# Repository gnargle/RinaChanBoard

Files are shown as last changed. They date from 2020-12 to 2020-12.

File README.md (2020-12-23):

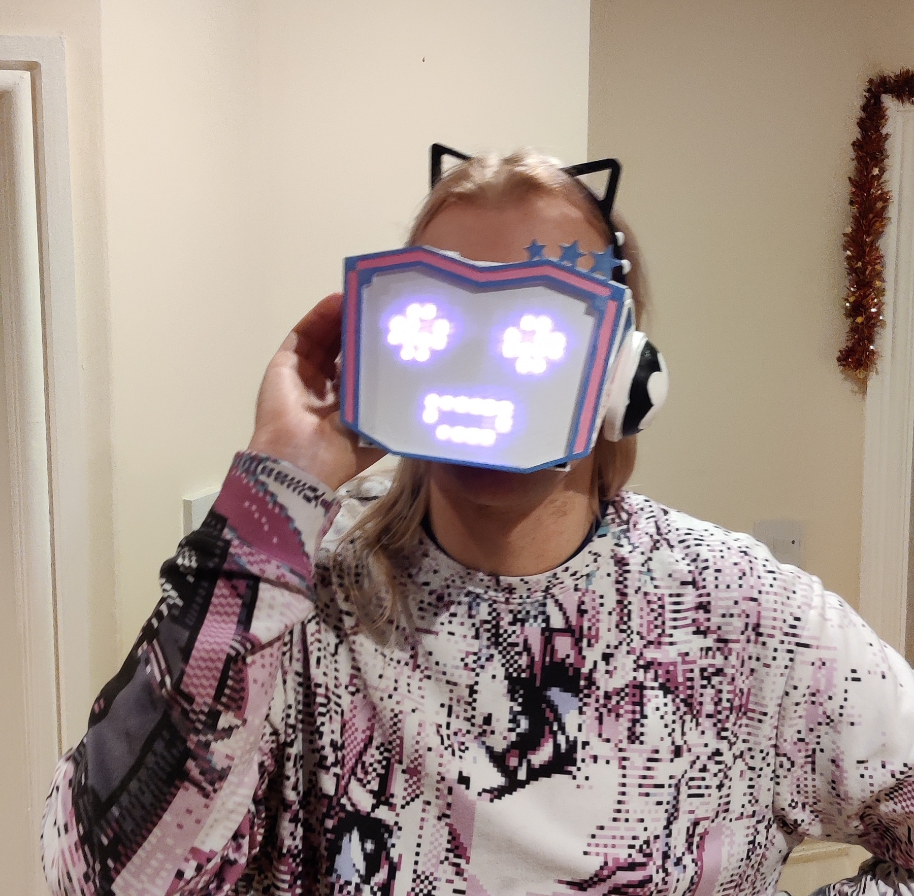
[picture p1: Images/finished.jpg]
Me wearing my new Rina-Chan Board!

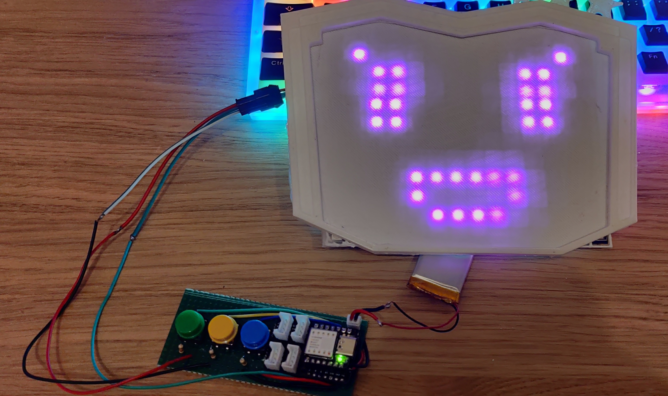
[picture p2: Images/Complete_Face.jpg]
Rina-Chan Board, Glowing and Smiling!


# RinaChanBoard
 Code, STLs and info to create a working Rina-Chan Board from Love Live!
 
## The Headset Model

The headset model was purchased from [Etsy](https://www.etsy.com/uk/listing/722676367/love-live-pdp-rina-tennoji-headset?transaction_id=2130833114). It's a brilliant model and fitted the exact purpose I needed it for. I highly recommend it.

The only STLs I am including are ones I personally modified to fit the use case (that is, creating a blank board and adding a grid to it). I am also including the diffuser.scad that I used - this is from thingiverse and is freely available. Use OpenSCAD to modify it to produce the size of grid you need, then attach it to the blank_plate.stl to create your grid. blank_grid.stl is the grid for the overlapped LED boards I used attached to the blank plate already.

Both are janky as hell, becasuse I don't know anything about modelling. 

## Required Hardware 
* Seeduino Xiao - This is the smallest arduino-compatible board I've found. https://www.seeedstudio.com/Seeeduino-XIAO-Arduino-Microcontroller-SAMD21-Cortex-M0+-p-4426.html
* 4x 8x8 WS2812B RGB LED boards - these will overlap but gives you a 14x13 LED area. It's enough to get good looking expressions for both eyes and face. You can also use 120 LED/m strips and manually lay them out and solder them. This will likely produce a better result, but the STL grid is not designed for that so you'll have to modify the blank plate yourself. https://www.aliexpress.com/item/32671025605.html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,searchweb201602_,searchweb201603_
* 3x push buttons. One each for selecting mouth and eyes, and one for confirming your selection. I didn't have any in so I bought this, which comes with button caps too. They are a little big so you might prefer smaller ones. https://www.amazon.co.uk/gp/product/B07Q22YP41/ref=ppx_yo_dt_b_asin_title_o04_s00?ie=UTF8&psc=1
* 3x 10k resistors - to tie the ground pin of the buttons.
* Wires, solder, etc
* OPTIONAL: Seeeduino Grove battery board. This is technically optional but I *highly* recommend it as it has a built in battery management board, with very little increase in used space. https://wiki.seeedstudio.com/Grove-Shield-for-Seeeduino-XIAO-embedded-battery-management-chip/
* OPTIONAL: LiPo battery. Doesn't need to be very big, I used this. https://www.amazon.co.uk/gp/product/B08215N9R8/ref=ppx_yo_dt_b_asin_image_o08_s01?ie=UTF8&psc=1
* OPTIONAL: JST connectors or Molex connectors for the battery. So you can easily disconnect it if needed. The above battery comes with a molex, I bought these JST connectors so had to solder the new connector on to it anyway because I'm an idiot and can't read. https://www.amazon.co.uk/gp/product/B07449V33P/ref=ppx_yo_dt_b_asin_image_o08_s00?ie=UTF8&psc=1

If you're not going to use the grove battery board you can roll your own battery solution but I found this was the easiest solution with very few drawbacks.

## Designing the Expressions

I used a hacked-together google docs sheet that I coloured in manually and copied the numbers out manually into arrays. There's definitely more clever ways of doing this but I hate working with spreadsheets so I was happy to be manual on this. What is useful in this case is I marked with outlines where the overlaps between the panels are. You can find my doc [here](https://docs.google.com/spreadsheets/d/1Beuz8oJ9O0KB6ERlhMPzRE0FvdVzDu4BHBZgB-ASULc/edit?usp=sharing). Use the adjusted spacing sheet - the first sheet is a full 16x16 matrix which has enough room for full model-accurate expressions. If you're going to use dense strips, I recommend a layout like this. Otherwise, use "adjusted spacing", sheet 2 ("Corrected Numbers") was an intermediary after I got the boards to actually layout the panels correctly, before I worked out any overlapping.

## Assembling the Board 

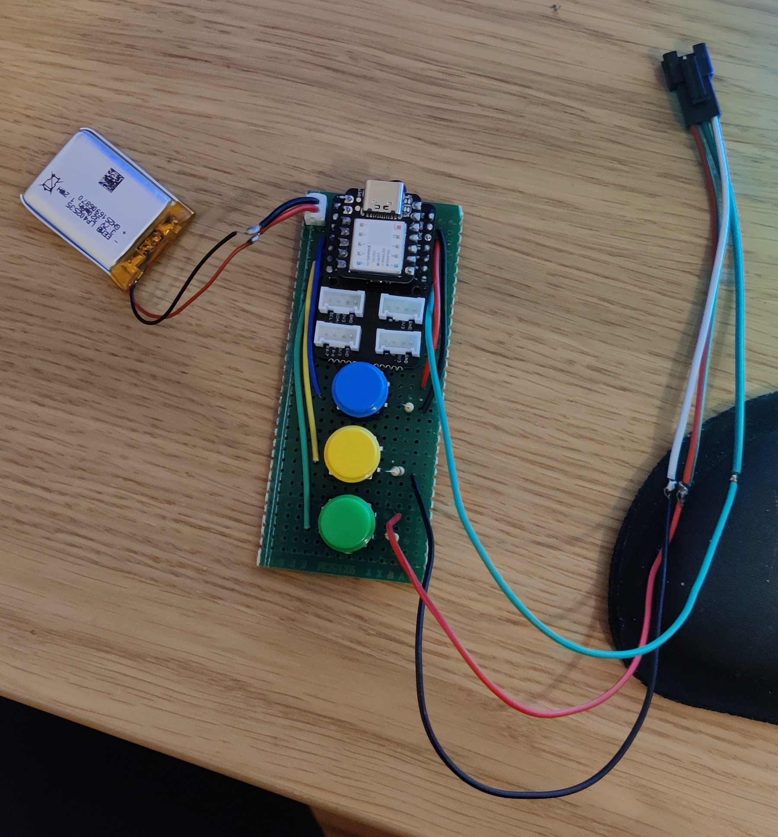
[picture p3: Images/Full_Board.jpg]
Full Board

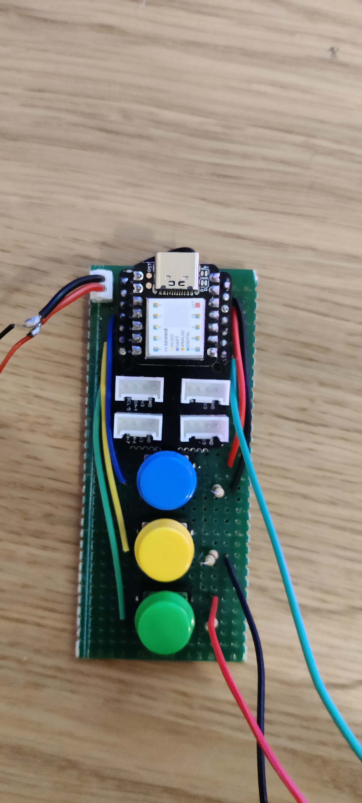
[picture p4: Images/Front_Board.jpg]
Front of the Board

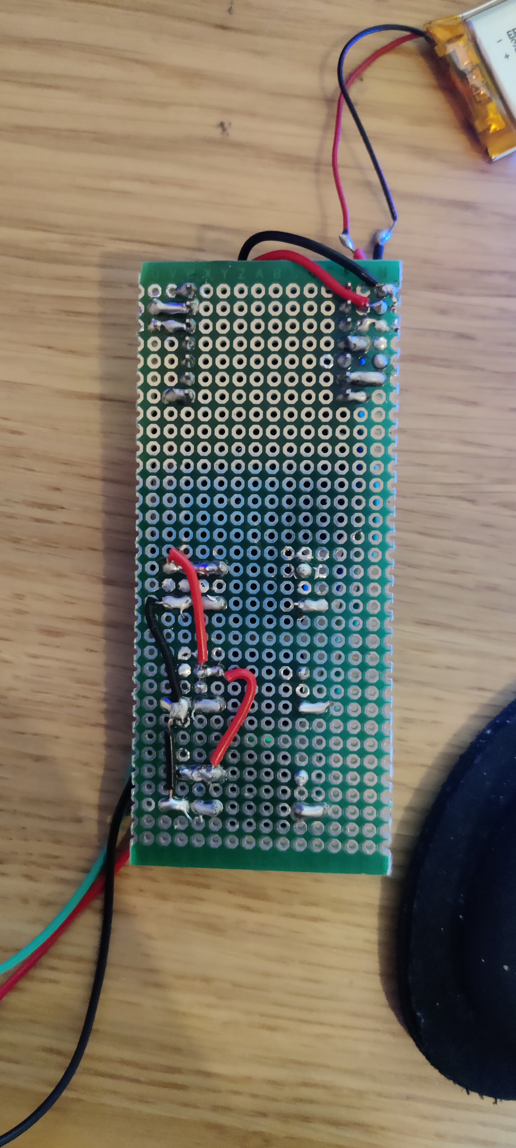
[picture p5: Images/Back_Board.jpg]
Back of the Board


My board is kind of a mess but the pinout is simple. Pins 3,5 and 6 are the buttons (these are modifiable consts in the code - they were originally 4,5 and 6 but I stripped the metal from the contact next to 4) and pin 7 (again, modifiable) is the output data line for the LED panels. The panels are 3-wire WS2812Bs, PWR/DIN/GRN. The ones I'm using run off 3.3v just fine - if you're using the battery board I recommend this as tying it to the 5v pin shares the power between the Seeeduino and the board, causing dim LEDs.

Each button has one pin to 3.3V and one pin to ground through a 10k resistor (see arduino's [button page](https://www.arduino.cc/en/Tutorial/BuiltInExamples/Button) for more info). The output pin from the button is the one opposite the ground pin.

Once the board is assembled, you can mount the battery in the earcup and glue the board to the side of the headset. The thickness of the plate with the boards attached are such that you will need to glue that in place inbetween the two halves of the front board from the model.

## Assembling the Expression Plate

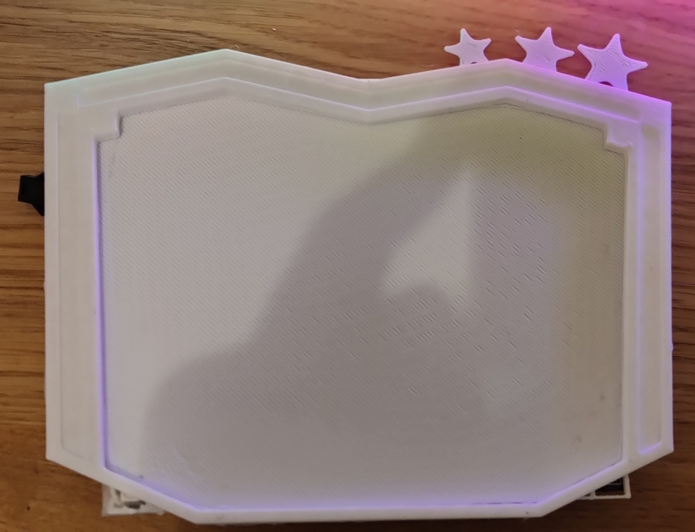
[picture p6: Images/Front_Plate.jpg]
Front Plate

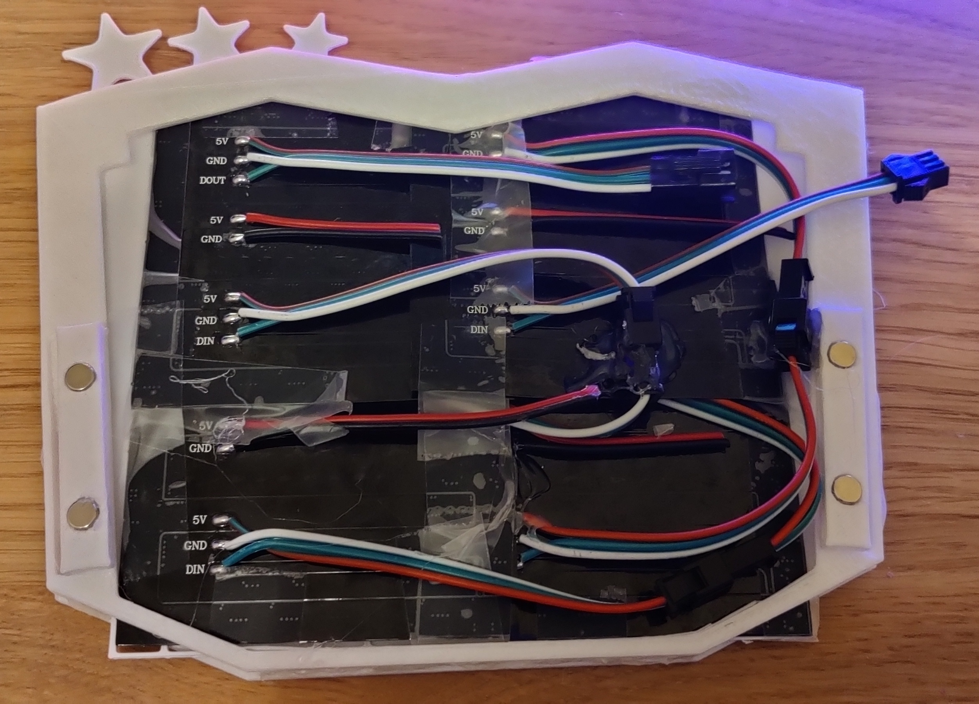
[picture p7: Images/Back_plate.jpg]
Back Plate


First, tape/glue your boards together in this format:

BOARD 1 | BOARD 4

BOARD 2 | BOARD 3

This means that in terms of LED order, the top left quadrant is first, then bottom left, then bottom right, then top right. Connect the DOUT -> DIN as appropriate along this pattern - the DIN for top left should be where the board connects, and the DOUT from top right should be unpopulated.

Then sandwich the two front plate holder parts either side of the LED plate and hot glue to hold it in place.

## The code

I've not worked on C++ in a long while (most of my work is in C# nowadays) and so I know the code is not the best it could be. the switch statements are particularly rubbish - I wanted to have a list of array pointers and just select them as appropriate but I couldn't get that working properly and the point of this project was the resultant prop, not nice code. So in this case, it working is enough for me. Feel free to PR a change that will make it cleaner if you want.

The code uses two Arduino librariers - FastLED and ezbutton. ezbutton works out the box but the version of FastLED in the arduino library does not support Seeeduino xiao (or didn't when I was working on this, anyway.). It's trivial to add this, though: (reproduced from https://forum.seeedstudio.com/t/xiao-using-fastled-to-control-ws2812b/252077/5 for posterity)

```
To get FastLED working you need to verify you are have the latest update to both the seeeduino boards as well as the FastLED library.

After verifying you have the most up to date versions of both.

Navigate into the FastLED library on your computer. Typically in C:\users<user name>\documents\arduino\libraries

you will want to navigate in the FastLED folder into the platforms then arm, then into d21, then edit the file called “fastpin_arm_d21”

Scroll down to around line 100 and paste this, and save.

#elif defined(SEEED_XIAO_M0)

#define MAX_PIN 10

_FL_DEFPIN( 0, 2,0); _FL_DEFPIN( 1, 4,0); _FL_DEFPIN( 2,10,0); _FL_DEFPIN( 3,11,0);

_FL_DEFPIN( 4, 8,0); _FL_DEFPIN( 5, 9,0); _FL_DEFPIN( 6, 8,1); _FL_DEFPIN( 7, 9,1);

_FL_DEFPIN( 8, 7,0); _FL_DEFPIN( 9, 5,0); _FL_DEFPIN(10, 6,0);

#define SPI_DATA 9

#define SPI_CLOCK 8

#define HAS_HARDWARE_PIN_SUPPORT 1
```
That will get it going. You'll also have to install the seeeduino boards list to flash to it but that's covered in Seeeduino's own docs, [here](https://wiki.seeedstudio.com/Seeeduino-XIAO/#getting-started).

## Credits

me lol. No but the only reason I could do this is inspiration from this [youtube vide](https://www.youtube.com/watch?v=0yT_qYHqlOU&feature=youtu.be), Porzellan Props, Love Live being so good, and support on other projects earlier this year from the cons & stuff discord.

If you have any questions on how I did any of this, I'm most easily reachable on [twitter](https://twitter.com/Thene_tho/)

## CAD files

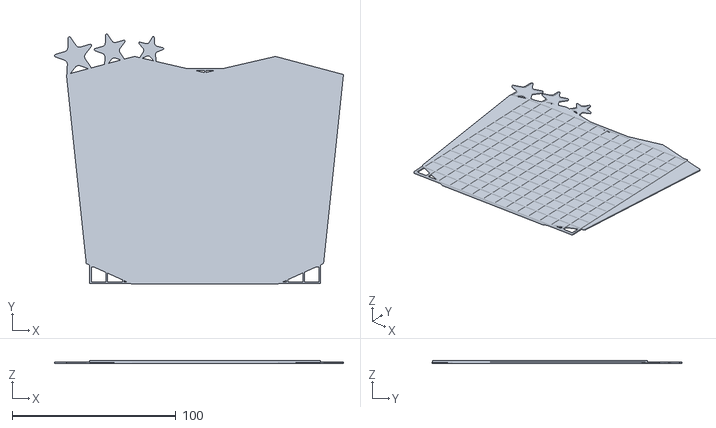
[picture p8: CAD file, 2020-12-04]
STLs/blank_grid.stl
176.2 x 152.6 x 2.08

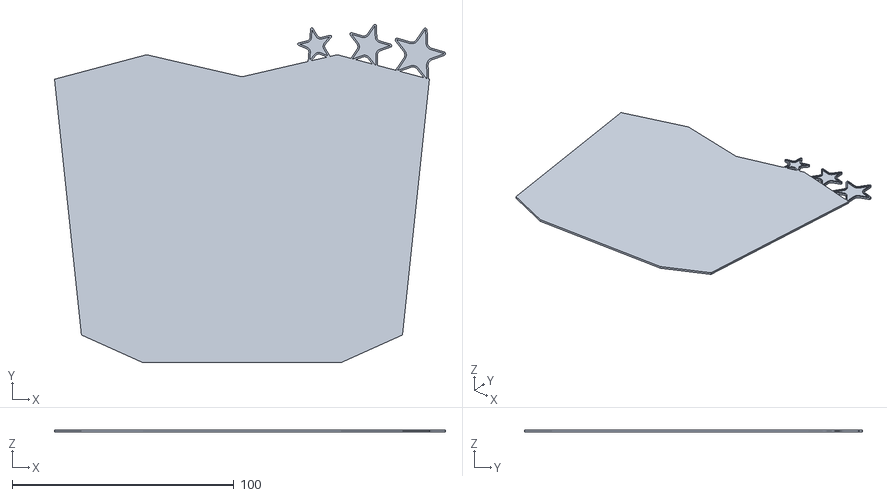
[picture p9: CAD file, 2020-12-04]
STLs/blank_board.stl
176.2 x 152.6 x 1.13

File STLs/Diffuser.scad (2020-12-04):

// WS2812 / WS2812b Led Matrix Diffuser by malebuffy

PCB_HEIGHT = 130; // Size of PCB in mm
PCB_WIDTH = 130; // Size of PCB in mm
NUMBER_LEDS_HORIZONTAL=16; // Number of Leds in a row
NUMBER_LEDS_VERTICAL=16;   // Number of Leds in a column
DIFFUSER_HEIGHT = 4; // Height of diffuser
LED_SIZE = 5; // Size of leds in mm
DISTANCE_BETWEEN_LEDS=3.12; // Distance between leds in mm
WALL_THINKESS=1; // Thinkess of walls
PCB_BORDER = 0.4;  // PCB Outer Boarder in mm

buffer=DISTANCE_BETWEEN_LEDS-WALL_THINKESS;


difference() {

cube([PCB_HEIGHT,PCB_WIDTH,DIFFUSER_HEIGHT]); // Create Main PCB Diffuser

for ( i = [0:NUMBER_LEDS_HORIZONTAL-1] ) {
    
    translate([PCB_BORDER,(LED_SIZE+DISTANCE_BETWEEN_LEDS)*i,-1])
    
    for ( j = [0:NUMBER_LEDS_VERTICAL-1] ) {
        
     translate([(LED_SIZE+DISTANCE_BETWEEN_LEDS)*j,PCB_BORDER,-1]) cube([LED_SIZE+buffer,LED_SIZE+buffer,DIFFUSER_HEIGHT+5]);   
        
        
        
  }
 }
}

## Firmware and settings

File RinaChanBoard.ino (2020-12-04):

#include <ezButton.h>
#include <FastLED.h>
#include <array>
#define NUM_LEDS 256 //4*8*8 BOARDS
#define ARRAY_SIZE(array) ((sizeof(array))/(sizeof(array[0]))) //why this works as a def micro but not a function, I do not know.
CRGB leds[NUM_LEDS];

int EYES_BLINK[] = {33,29,28,27,26,230,221,220,219,218,/*99,100,101,102,103,162,163,164,92,155,84,85,86,87,146,147*/};
int EYES_CONTENT[] = {30,125,124,27,220,187,186,217};
int EYES_SMILE[] = {46,34,35,29,28,125,124,114,115,233,228,229,219,218,187,186,180,181};
int EYES_UWU[] {47,46,34,35,27,125,124,112,113,183,182,187,186,220,228,229,233,232};
int EYES_O[] {34,35,30,29,27,126,125,124,123,114,115,228,229,220,218,217,188,187,186,185,180,181};

int MOUTH_CONTENT[] = {93,83,75,74,73,72,141,140,148,154};
int MOUTH_SMILE[] = {91,90,89,88,84,74,73,72,141,147,157,156};
int MOUTH_UWU[] {84,74,73,72,141,147};
int MOUTH_O[] {105,104,101,162,91,156,85,146,73,72};

int eyeSelect = 0;
int eyeCurrent = 0;
int mouthSelect = 0;
int mouthCurrent = 0;

int eyeButtonState = 0;
int mouthButtonState = 0;
int confirmButtonState = 0;
int eyeButtonLastState = 0;
int mouthButtonLastState = 0;
int confirmButtonLastState = 0;

unsigned long startMillis;  //some global variables available anywhere in the program
unsigned long currentMillis;
bool blinking = false;

//Consts. Customize these according to the pins your buttons and LED data are on, how sensitive to deboundce your buttons are,
//and how long you want Rina to go between blink (and how long those blinks should last!)
const unsigned long blinkPeriod = 5000;  //the value is a number of milliseconds
const unsigned long blinkLength = 500;
const int eyePin = 3;
const int mouthPin = 5;
const int confirmPin = 6; // the number of the pushbutton pin
const int ledPin =  13;      // the number of the LED pin
const int debounceTime = 50;

ezButton eyeButton(eyePin);
ezButton mouthButton(mouthPin);
ezButton confirmButton(confirmPin);

//the boards zigzag
//layout is like this:
//15,14,13,12,11,10,9,8
//0,1,2,3,4,5,6,7
//with all the labels on the board rightside up.
void setup() {
  // put your setup code here, to run once:
  FastLED.addLeds<NEOPIXEL, 7>(leds, NUM_LEDS);
  pinMode(ledPin, OUTPUT);    
  eyeButton.setDebounceTime(debounceTime);
  mouthButton.setDebounceTime(debounceTime);
  confirmButton.setDebounceTime(debounceTime);  
  updateFace();
  startMillis = millis(); 
}

void clearFace() {
  for (int i = 0; i < NUM_LEDS ; i++) {
    leds[i] = CRGB::Black ;
  }
}

void lightFace(int face[]) {
  int length = 0;
}

void lightFace(int face[], int arraySize) {
  for (int i = 0; i < arraySize; i++) {
    leds[face[i]] = CRGB::DeepPink;
    leds[face[i]].fadeLightBy(32);
  }
  FastLED.show();
}

void updateEyes(){
  switch(eyeCurrent){    
    case 1:
      changeFace(EYES_SMILE, ARRAY_SIZE(EYES_SMILE));
      break;
    case 2:
      changeFace(EYES_UWU, ARRAY_SIZE(EYES_UWU));
      break;
    case 3:
      changeFace(EYES_O, ARRAY_SIZE(EYES_O));
      break;
    default:
      changeFace(EYES_CONTENT, ARRAY_SIZE(EYES_CONTENT));
      break;
  }
  delay(25);
}
void updateMouth(){
  switch(mouthCurrent){    
    case 1:
      changeFace(MOUTH_SMILE, ARRAY_SIZE(MOUTH_SMILE));
      break;
    case 2:
      changeFace(MOUTH_UWU, ARRAY_SIZE(MOUTH_UWU));
      break;  
    case 3:
      changeFace(MOUTH_O, ARRAY_SIZE(MOUTH_O));
      break;
    default:
      changeFace(MOUTH_CONTENT, ARRAY_SIZE(MOUTH_CONTENT));
      break;
  }
  delay(25);
}

void updateFace(){
  clearFace();
  updateEyes();
  updateMouth();  
}

void changeFace(int face[], int faceSize) {
  lightFace(face, faceSize);
}

void loop() {
  eyeButton.loop();
  mouthButton.loop();
  confirmButton.loop();
  eyeButtonState = eyeButton.getState();
  mouthButtonState = mouthButton.getState();
  confirmButtonState = confirmButton.getState();
  
  if (eyeButtonLastState != eyeButtonState){
    if (eyeButtonState == HIGH){
      eyeSelect++;
    }
    eyeButtonLastState = eyeButtonState;
  }
  if (mouthButtonLastState != mouthButtonState){
    if (mouthButtonState == HIGH){
      mouthSelect++;
    }
    mouthButtonLastState = mouthButtonState;
  }

  if (confirmButtonLastState != confirmButtonState){  
    if (confirmButtonState == HIGH){
      eyeCurrent = eyeSelect;
      mouthCurrent = mouthSelect;
      eyeSelect = 0;
      mouthSelect = 0;
      updateFace();
    }
    confirmButtonLastState = confirmButtonState;
    startMillis = millis(); 
  } else {
    //only blink if we haven't just changed.
    currentMillis = millis(); 
    if (blinking) {
      if (currentMillis - startMillis >= blinkLength){
        updateFace();
        startMillis = currentMillis;
        blinking = false;
      }
    } else if (currentMillis - startMillis >= blinkPeriod)
    {
      clearFace();
      changeFace(EYES_BLINK, ARRAY_SIZE(EYES_BLINK));
      delay(25);
      updateMouth(); //keep mouth in place!
      startMillis = currentMillis;
      blinking = true;
    }
  }
}
